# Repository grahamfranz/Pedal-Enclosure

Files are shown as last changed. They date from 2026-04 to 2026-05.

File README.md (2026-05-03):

# Parametric Guitar Pedal Enclosure

A fully customizable 3D-printable guitar pedal enclosure designed in OpenSCAD, inspired by classic Hammond die-cast boxes. Create professional-looking enclosures in multiple standard sizes or define your own custom dimensions.

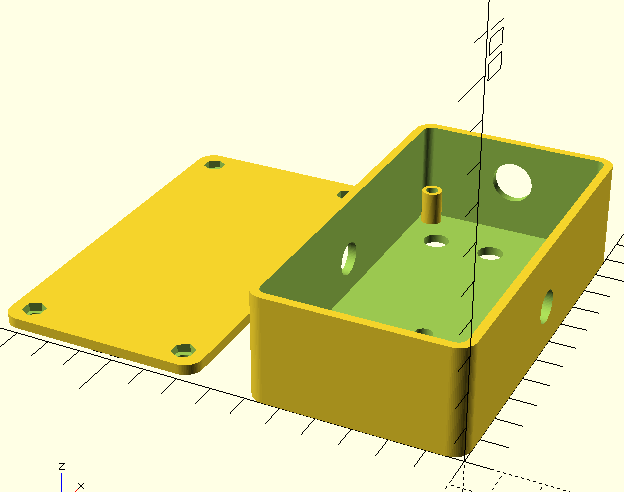
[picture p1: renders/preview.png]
Pedal Enclosure Preview


## Features

- **Parametric Design**: Adjust every dimension and component hole size via the OpenSCAD Customizer
- **Multiple Presets**: Choose from Hammond standard sizes (1590A, 1590B, 1590BB, 125B) or design custom dimensions
- **Two-Part Assembly**: Open-bottom shell with removable lid for easy component mounting
- **Complete Controls**: Pre-configured holes for:
  - Potentiometer knobs (configurable count and positions)
  - Footswitch
  - LED indicator
  - 1/4" input and output audio jacks
  - DC barrel jack for power
- **Screw Bosses**: Built-in corner screw mounting posts with configurable counterbores
- **Smooth Curves**: Rounded corners and edges for a professional finish
- **Print-Ready**: Includes flipping options to optimize for 3D printing

## Getting Started

### Requirements

- **OpenSCAD** (free, open-source 3D CAD tool): [Download](https://openscad.org/)
- A 3D printer or 3D printing service

### Installation

1. Clone the repository:
   ```bash
   git clone https://github.com/grahamfranz/Pedal-Enclosure.git
   cd Pedal-Enclosure
   ```

2. Open `pedal_enclosure.scad` in OpenSCAD

## Usage

### Quick Start with Presets

1. In OpenSCAD, go to **Window > Customizer**
2. Under the `[Preset]` section, select a preset size:
   - `1590A` - Small (92.5 × 38.5 × 31 mm)
   - `1590B` - Medium (112 × 60 × 31 mm) — *default*
   - `1590BB` - Large (119 × 94 × 34 mm)
   - `125B` - XL (121 × 66 × 39 mm)
3. Choose a render option under `[Render]`:
   - `enclosure` - Just the main shell (top side up)
   - `lid` - Just the bottom plate (base plate up)
   - `both` - Both parts positioned for printing (with default flip options)
   - `assembled` - Parts together to see the final result
4. The default settings use **hex nut fasteners, board standoffs enabled, no corner bosses, and flipped print orientation** — ideal for most builds
5. Click **F5** to preview or **F6** to render
6. Export as STL when ready to print

### Custom Dimensions

1. Set `preset` to `custom`
2. Enter your desired dimensions in the `[Custom Outer Size]` section:
   - `custom_length` - X axis (long direction)
   - `custom_width` - Y axis (short direction)
   - `custom_height` - Z axis (vertical)

### Customize Components

The Customizer provides sections for fine-tuning:

- **[Shell]** - Wall thickness, corner radius, smoothness
- **[Screw Mounting]** - Boss type (on/off), diameter, inset, clearances, counterbores, and fastener type (`self_tap`, `hex_nut`, `square_nut`)
- **[Lid Locating Lip]** - A raised plug on the lid that drops into the enclosure cavity, preventing lid shear under foot pressure
- **[Board Mount]** - Standoff diameter and height (optional posts hanging from the top wall for proto board mounting)
- **[Top: Knobs]** - Number of knobs (auto-distributes across rows), center-to-center spacing, hole diameter, row spacing
- **[Top: Footswitch]** - Hole size and position
- **[Top: LED]** - Hole diameter and position (optional)
- **[Sides: Audio Jacks]** - Hole sizes, heights, and symmetric offset to prevent jack hardware collision
- **[Back: DC Jack]** - Hole size and height (optional)

### Coordinate System

The design uses a standard orientation (top-down view):

```
      +X  (back edge — DC jack)
   +-------------------+
   |       [dc]        |
   |  o   o   o   o    | knob row
[O]|                   |[I] -Y = output, +Y = input
   |        *          | LED
   |                   |
   |       ( X )       | footswitch
   |                   |
   +-------------------+
      -X  (toe)
```

## Printing Tips

- **Enclosure orientation**: Controlled by `flip_enclosure_for_print` (default `true` — top face on bed for the cleanest finish on the labeled side)
- **Lid orientation**: Controlled by `flip_lid_for_print` (default `true` — nut pockets face upward, away from the bed, so they don't sag during printing; the raised locating plug prints first as a solid foundation)
- **Support Material**: With both flip options on, neither part needs supports
- **Tolerance**: Adjust `lid_clearance_d` and `screw_hole_d` if you have fit issues with your printer
- **Wall Thickness**: For durability, keep at least 2–2.5 mm walls
- **Lid thickness**: Use at least 3 mm when using hex/square nut modes; the raised lip will be `lip_height` taller (default 1.5 mm)
- **Locating lip fit**: The plug is sized to the cavity inner profile minus 0.3 mm clearance so it slips in smoothly without binding

## Assembly

### Fastener Options

Choose a method in the `[Screw Mounting]` section:

| `boss_fastener` | Hardware needed | Notes |
|---|---|---|
| `self_tap` | M3 self-tapping screws (from below) | Simple, but repeated opening/closing will eventually strip the plastic |
| `hex_nut` *(default)* | M3 hex nuts + M3 machine screws (from above) | Screw enters the top face, passes down through the corner, and threads into a hex nut pocket captive in the lid's underside — provides reusable fastening |
| `square_nut` | M3 square nuts + M3 machine screws (from above) | Same as hex, but with a square pocket which is easier to print accurately |

**Note:** Nut modes recess the nut pocket into the lid's underside, so set `lid_thickness` to at least `nut_pocket_depth + 0.6` mm (default 3 mm is recommended for M3).

For nut modes, set `nut_pocket_depth` to match your nut (hex ≈ 2.4 mm, square ≈ 1.8 mm).

### Assembly Steps

1. Print both parts (use default flip settings for cleanest results)
2. *(Hex/square nut modes only)* Drop an M3 nut into each nut pocket on the lid's underside
3. Install your components (pots, jacks, footswitch, LED) into the pre-drilled holes
4. *(Optional: board standoffs)* Insert your proto board (e.g., CircuitMesh) from below the enclosure, aligning its screw holes with the standoffs, then secure from underneath
5. Insert screws from the top into the corner posts and tighten (they will thread into the nut pockets on the lid's underside)
6. Mount the lid to close the enclosure — the raised locating plug will drop into the cavity for a snug, shear-resistant fit

## Pre-Rendered STL Files

All preset Hammond enclosures are available as pre-rendered STLs in the `renders/` directory, ready for immediate 3D printing. Each preset is exported in three configurations:

| Preset | Size (mm) | Enclosure | Lid | Both |
|---|---|---|-----|---|
| **1590A** | 92.5 × 38.5 × 31 | `1590A_enclosure.stl` | `1590A_lid.stl` | `1590A_both.stl` |
| **1590B** | 112 × 60 × 31 | `1590B_enclosure.stl` | `1590B_lid.stl` | `1590B_both.stl` |
| **1590BB** | 119 × 94 × 34 | `1590BB_enclosure.stl` | `1590BB_lid.stl` | `1590BB_both.stl` |
| **125B** | 121 × 66 × 39 | `125B_enclosure.stl` | `125B_lid.stl` | `125B_both.stl` |

**Note**: All presets default to 3 knobs. You can customize `num_knobs` in the Customizer for any preset — the layout automatically wraps to multiple rows as needed.

### Quick Print Guide

- **Use `*_both.stl` files** for a complete assembly view with both parts positioned for printing
- **Use individual `*_enclosure.stl` and `*_lid.stl` files** if you prefer to print them separately or scale one part differently

## File Structure

```
Pedal-Enclosure/
├── README.md                  # This file
├── LICENSE                    # MIT License
├── pedal_enclosure.scad       # Main OpenSCAD design
└── renders/
    ├── preview.png            # Visual preview
    ├── 1590A_enclosure.stl     # Pre-rendered STL (small, 2 knobs)
    ├── 1590A_lid.stl
    ├── 1590A_both.stl
    ├── 1590B_enclosure.stl     # Pre-rendered STL (medium, 3 knobs)
    ├── 1590B_lid.stl
    ├── 1590B_both.stl
    ├── 1590BB_enclosure.stl    # Pre-rendered STL (large, 3 knobs)
    ├── 1590BB_lid.stl
    ├── 1590BB_both.stl
    ├── 125B_enclosure.stl      # Pre-rendered STL (XL, 3 knobs)
    ├── 125B_lid.stl
    └── 125B_both.stl
```

## Customization Examples

### Reduce Material: Thin-Walled Version
- Decrease `wall_thickness` to 1.5 mm
- Decrease `lid_thickness` to 1.2 mm

### Smoother Finish: High-Detail Render
- Increase `facets` from 72 to 96 or higher (slower render)

### More Knobs
- Increase `num_knobs` to any value. The layout automatically wraps knobs to multiple rows based on enclosure width
- Adjust `knob_spacing` (center-to-center distance) and `knob_row_spacing` (vertical gap between rows) as needed
- Rows with different knob counts are horizontally centered (staggered effect); rows with the same count align vertically

### Offset Audio Jacks
- Use `jack_x_offset` to prevent 1/4" jack connectors from colliding (typical range: ±15 mm)
- Positive values move the input jack forward and output jack back
- Negative values reverse the direction
- Useful for compact builds where jack hardware extends into the enclosure

### Hide Optional Components
- Set `include_led` to `false` to remove the LED hole
- Set `include_dc_jack` to `false` to remove the DC jack

## Contributing

Feel free to fork, modify, and share improvements. If you have suggestions or find issues, please open an issue on GitHub.

## Credits

Designed by Graham Franz. Inspired by the classic Hammond die-cast enclosure series.

---

**Tips**: For the best results, always preview your design in OpenSCAD before printing. Test-fit your components (pots, jacks) in the STL file to ensure proper spacing and clearance.

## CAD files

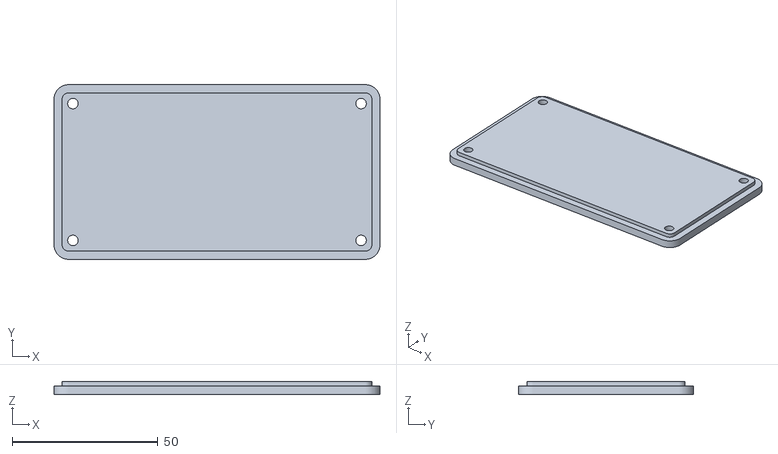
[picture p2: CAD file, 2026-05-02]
renders/1590B_lid.stl
112.0 x 60.0 x 4.50

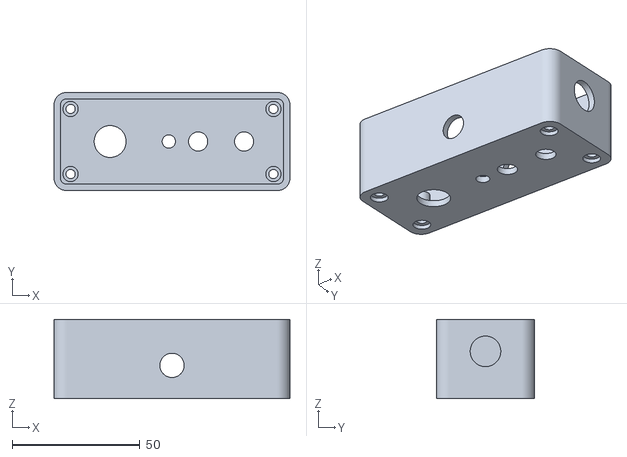
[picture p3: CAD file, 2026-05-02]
renders/1590A_enclosure.stl
92.5 x 38.5 x 31.0

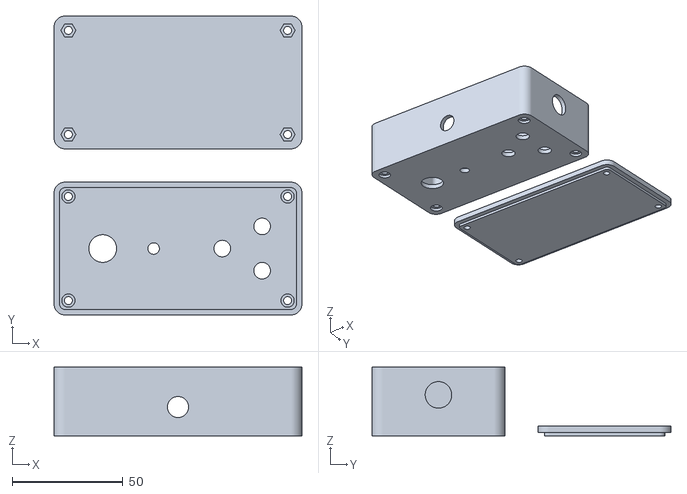
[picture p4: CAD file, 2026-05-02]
renders/1590B_both.stl
112.0 x 135.0 x 31.0

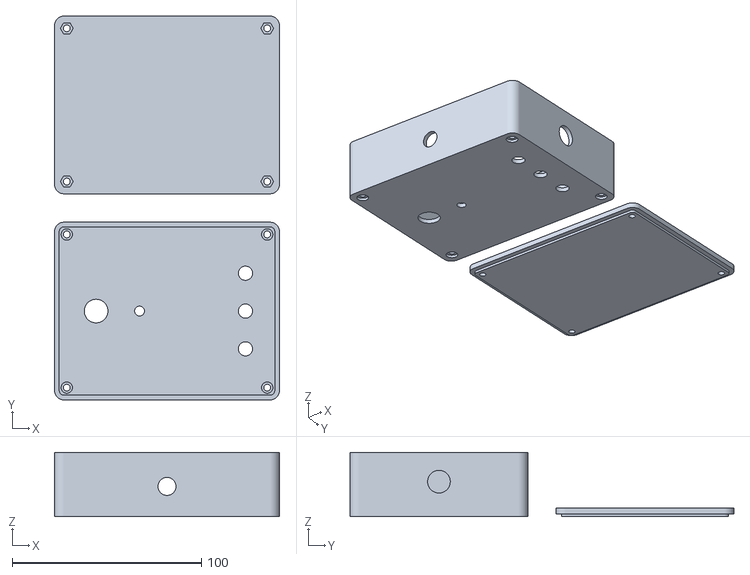
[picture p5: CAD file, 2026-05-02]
renders/1590BB_both.stl
119.0 x 203.0 x 34.0

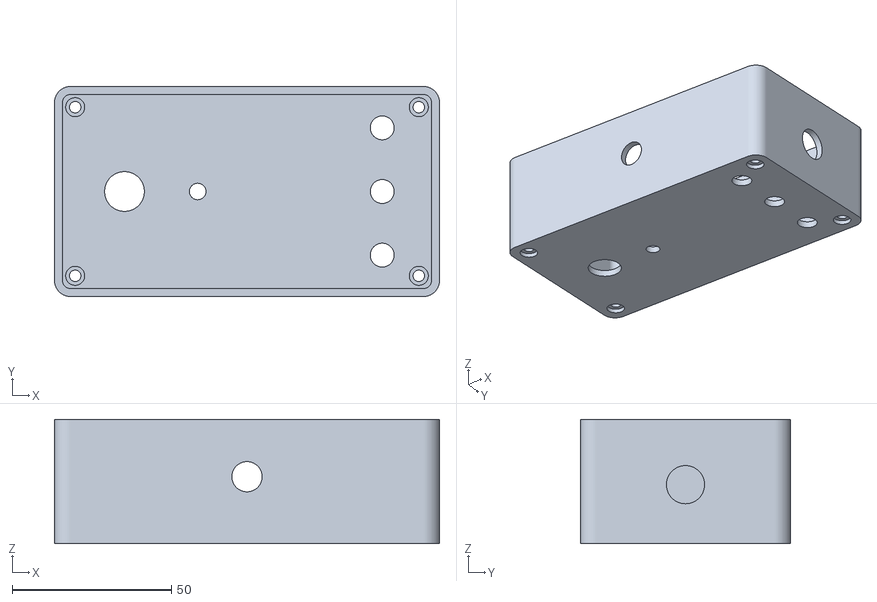
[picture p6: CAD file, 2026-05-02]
renders/125B_enclosure.stl
121.0 x 66.0 x 39.0

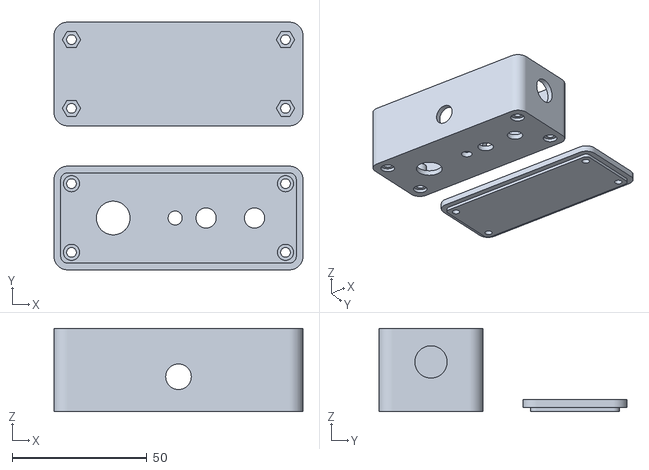
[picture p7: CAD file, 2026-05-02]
renders/1590A_both.stl
92.5 x 92.0 x 31.0

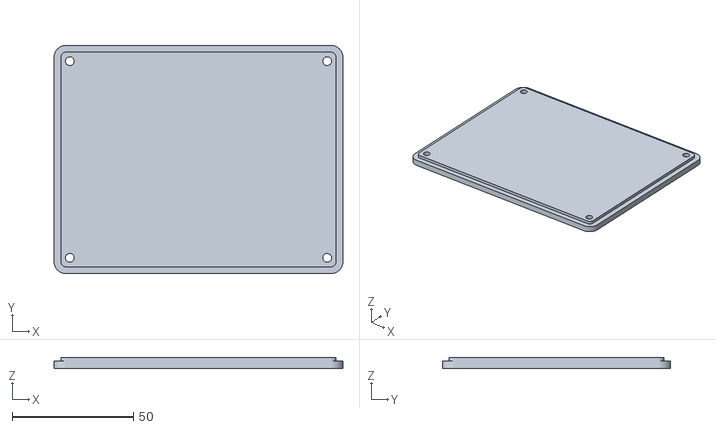
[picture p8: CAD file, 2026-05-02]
renders/1590BB_lid.stl
119.0 x 94.0 x 4.50

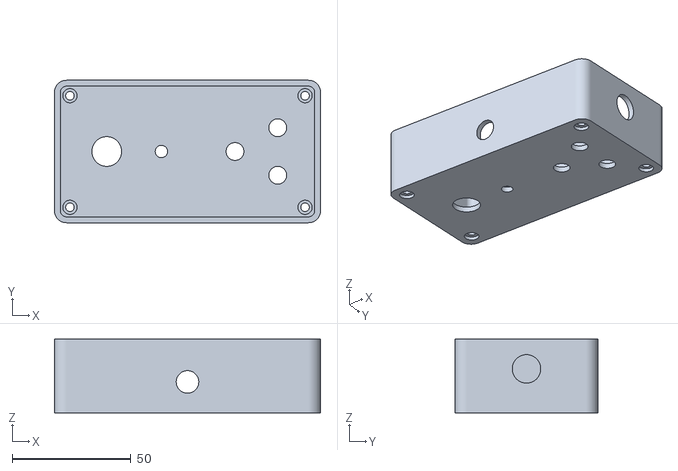
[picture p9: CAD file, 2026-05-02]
renders/1590B_enclosure.stl
112.0 x 60.0 x 31.0

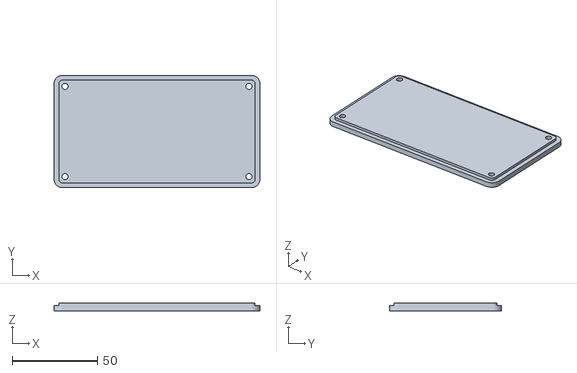
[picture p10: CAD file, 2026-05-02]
renders/125B_lid.stl
121.0 x 66.0 x 4.50

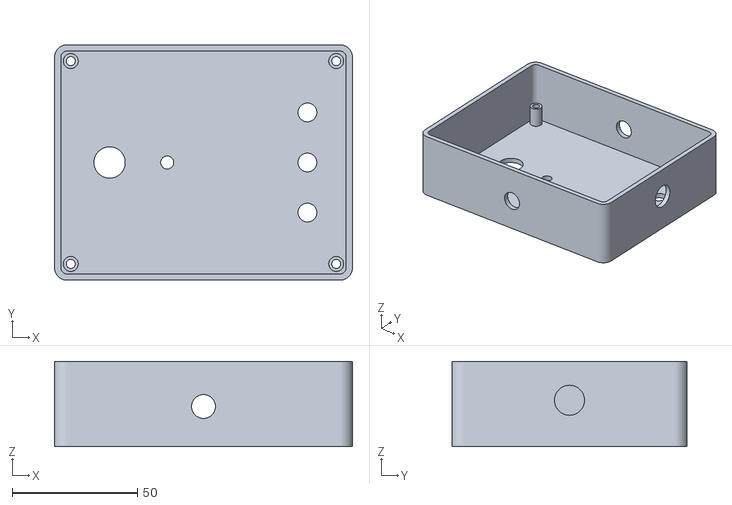
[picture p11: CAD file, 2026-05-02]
renders/1590BB_enclosure.stl
119.0 x 94.0 x 34.0

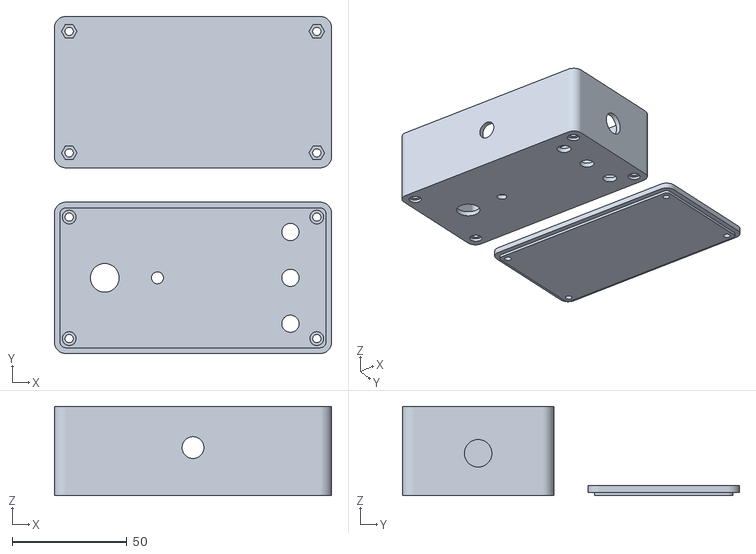
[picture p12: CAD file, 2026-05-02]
renders/125B_both.stl
121.0 x 147.0 x 39.0

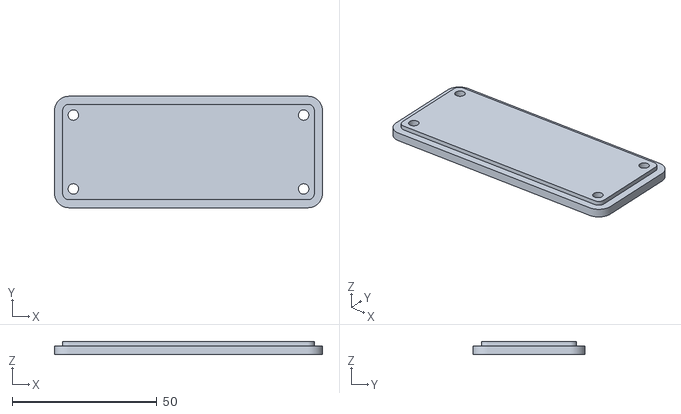
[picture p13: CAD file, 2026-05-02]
renders/1590A_lid.stl
92.5 x 38.5 x 4.50

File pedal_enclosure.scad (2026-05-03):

/* ============================================================
 *  Parametric Guitar Pedal Enclosure
 *  ------------------------------------------------------------
 *  Inspired by Hammond die-cast boxes (1590A / 1590B / 1590BB /
 *  125B). Open-bottom shell with a removable lid, corner screw
 *  bosses, and all the usual holes for pots, footswitch, LED,
 *  1/4" jacks and a DC barrel jack.
 *
 *  Layout (top-down view, looking at the top face):
 *
 *        +X  <-- back edge (DC jack)
 *     +-------------------+
 *     |       [dc]        |
 *     |  o   o   o   o    |   knob row
 *  [O]|                   |[I]   -Y = output,  +Y = input
 *     |        *          |   LED
 *     |                   |
 *     |       ( X )       |   footswitch
 *     |                   |
 *     +-------------------+
 *        -X  <-- toe
 *
 *  Tweak everything in the Customizer panel (Window > Customizer
 *  in OpenSCAD) or edit the variables below.
 * ============================================================ */

/* [Preset] */
// Pick a common Hammond size, or choose "custom" to use the fields below.
preset = "1590B"; // [custom, 1590A, 1590B, 1590BB, 125B]

/* [Render] */
// Which part to render.
part = "both"; // [enclosure, lid, both, assembled]
// Flip the enclosure so the top face is on the bed (cleanest finish for the
// labeled face). Either way each part's print-bottom sits on Z = 0.
flip_enclosure_for_print = true;
// Flip the lid so any recesses (nut pockets or counterbores) face away from
// the bed — they bridge cleanly when printed open-side up.
flip_lid_for_print = true;

/* [Custom Outer Size — used when preset = "custom"] */
custom_length = 112;  // along X (long axis)
custom_width  = 60;   // along Y
custom_height = 31;   // along Z

/* [Shell] */
wall_thickness = 2.5;
lid_thickness  = 3.0;  // bump to ≥ nut_pocket_depth + 0.6 mm when using nut modes
corner_radius  = 5;
// Smoothness — higher = prettier curves, slower render.
facets = 72;

/* [Lid Locating Lip] */
// A stepped flange on the lid perimeter that sits on the enclosure rim,
// preventing shear and keeping the lid aligned.
include_lip = true;
lip_height  = 1.5;  // height of the perimeter flange (mm)

/* [Screw Mounting] */
// How the lid screws fasten into the corner bosses.
include_screw_bosses = false; // set false to free corner space for a full-width board
boss_fastener   = "hex_nut"; // [self_tap, hex_nut, square_nut]
screw_hole_d    = 2.7;   // pilot hole for self_tap (M3 → 2.7 mm)
screw_boss_d    = 8;     // corner boss outside diameter
screw_inset     = 6;     // distance from outer wall to boss centre
lid_clearance_d = 3.6;   // M3 free-fit through the lid (also used as boss clearance for nut modes)
lid_counterbore = true;  // recess the screw heads into the lid
// Nut pocket — used when boss_fastener is "hex_nut" or "square_nut".
// Pocket is recessed into the BOTTOM (outside) face of the lid, so make sure
// lid_thickness is at least nut_pocket_depth + ~0.6 mm of plastic on top.
nut_af          = 5.5;   // across-flats dimension (M3 standard hex/square = 5.5 mm)
nut_pocket_depth = 2.4;  // M3 hex ≈ 2.4 mm, M3 square ≈ 1.8 mm

/* [Board Mount] */
// Raised standoffs inside the enclosure for mounting a CircuitMesh or other proto board.
board_standoffs       = true;
board_standoff_height = 10;   // distance from the top-wall underside to the board (mm)
board_standoff_d      = 6;    // standoff post diameter (mm)
board_screw_margin    = 4;    // from inner wall corner to standoff centre — match your board's value
board_pilot_d         = 2.7;  // M3 self-tap pilot drilled up into the standoff

/* [Top: Knobs] */
num_knobs          = (preset == "1590A") ? 2 : 3;  // auto-adjust for tight 1590A, override in Customizer if needed
knob_hole_d        = 7.5;   // 3/8" pot bushing clearance
knob_spacing       = 20;    // center-to-center distance between knob holes (static, doesn't scale)
knob_row_spacing   = 18;    // center-to-center vertical distance between knob rows
knob_row_from_back = 18;    // distance of first (topmost) knob row from +X wall
knob_side_margin   = 13;    // distance from first/last knob to long side (Y axis)

/* [Top: Footswitch] */
footswitch_hole_d     = 12.5;  // 12 mm stomp switch
footswitch_from_front = 22;    // distance from -X wall

/* [Top: LED] */
include_led    = true;
led_hole_d     = 5.2;    // 5 mm LED pass-through (use ~8.2 for bezel)
led_from_front = 45;

/* [Sides: Audio Jacks] */
input_jack_d         = 9.5;   // 1/4" enclosed jack
output_jack_d        = 9.5;
jack_height_from_lid = 15;    // centre height above the lid seat
jack_x_offset        = 0;     // symmetric offset in mm; positive = input forward, output back
                              // typical range: ±15 mm (beyond ±20 mm risks hitting walls/bosses)

/* [Back: DC Jack] */
include_dc_jack        = true;
dc_jack_d              = 12;   // 2.1 mm barrel jack with panel boss
dc_jack_board_offset   = -6;    // barrel jack centre height above the board surface

/* [Hidden] */
$fn = facets;
EPS = 0.02;

// ============================================================
//  Geometry
// ============================================================

function _preset_dims() =
    preset == "1590A"  ? [92.5, 38.5, 31] :
    preset == "1590B"  ? [112,   60,   31] :
    preset == "1590BB" ? [119,   94,   34] :
    preset == "125B"   ? [121,   66,   39] :
                         [custom_length, custom_width, custom_height];

_dims = _preset_dims();
L = _dims[0];
W = _dims[1];
H = _dims[2];

// Auto-calculate DC jack height to align with a board-mounted barrel jack.
dc_jack_height_from_lid = H - wall_thickness - board_standoff_height + dc_jack_board_offset - lid_thickness;

echo(str("Outer size: ", L, " x ", W, " x ", H, " mm"));

// Sanity check: nut pocket must fit inside the lid with some plastic on top.
if ((boss_fastener == "hex_nut" || boss_fastener == "square_nut")
    && lid_thickness < nut_pocket_depth + 0.6)
    echo(str("WARNING: lid_thickness (", lid_thickness,
             ") is too thin for the ", boss_fastener, " pocket (",
             nut_pocket_depth, " mm). Bump lid_thickness to at least ",
             nut_pocket_depth + 0.6, " mm."));

// ---------- helpers ----------

module rounded_prism(l, w, h, r) {
    rr = max(0.1, min(r, min(l, w) / 2 - 0.1));
    hull() for (x = [rr, l - rr], y = [rr, w - rr])
        translate([x, y, 0]) cylinder(r = rr, h = h);
}

function _corner_points() = [
    [screw_inset,     screw_inset    ],
    [L - screw_inset, screw_inset    ],
    [screw_inset,     W - screw_inset],
    [L - screw_inset, W - screw_inset]
];

function _board_standoff_points() = [
    [wall_thickness + board_screw_margin, wall_thickness + board_screw_margin              ],
    [L - wall_thickness - board_screw_margin, wall_thickness + board_screw_margin          ],
    [wall_thickness + board_screw_margin, W - wall_thickness - board_screw_margin          ],
    [L - wall_thickness - board_screw_margin, W - wall_thickness - board_screw_margin      ]
];

// Multi-row knob layout helpers.
// Calculate how many knobs fit in one row given available width.
function _knobs_per_row() =
    num_knobs == 0 ? 0 :
    let(available_width = W - 2 * knob_side_margin)
    floor((available_width + knob_spacing) / knob_spacing);

// Calculate the actual row spacing, auto-reducing if enclosure is too short.
function _effective_knob_row_spacing() =
    let(kpr = _knobs_per_row(),
        num_rows = kpr == 0 ? 0 : ceil(num_knobs / kpr))
    num_rows <= 1 ? knob_row_spacing :
    let(available_length = L - knob_row_from_back - led_from_front - knob_hole_d/2 - led_hole_d/2 - 5,
        max_spacing = available_length / max(1, num_rows - 1))
    min(knob_row_spacing, max_spacing);  // Use calculated spacing if smaller

// Return list of [x, y, row, col] for each knob position.
function _knob_positions() =
    let(kpr = _knobs_per_row(),
        available_width = W - 2 * knob_side_margin,
        effective_spacing = _effective_knob_row_spacing())
    kpr == 0 ? [] :
    [for (i = [0 : num_knobs - 1])
        let(row = floor(i / kpr),
            col = i - row * kpr,
            knobs_in_row = min(kpr, num_knobs - row * kpr),
            // Width occupied by knobs in this row
            row_width = (knobs_in_row - 1) * knob_spacing,
            // Center offset to align row to enclosure
            row_offset_y = (available_width - row_width) / 2,
            // Y position (centered per row, then add side margin)
            yk = knob_side_margin + row_offset_y + col * knob_spacing,
            // X position (from back, accounting for row with effective spacing)
            xk = L - knob_row_from_back - row * effective_spacing)
        [xk, yk, row, col]
    ];
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

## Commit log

2026-04-28 Initial commit: parametric pedal enclosure with preset Hammond sizes
    Fully customizable guitar pedal enclosure with:
    - 4 preset Hammond sizes (1590A, 1590B, 1590BB, 125B)
    - Pre-rendered STL files ready for 3D printing
    - Complete OpenSCAD parametric design
    - Support for custom dimensions and components
    [125B_both.stl, 125B_enclosure.stl, 125B_lid.stl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]
2026-05-02 Add multi-row knob layout support
    - Add knob_spacing (static center-to-center spacing) and knob_row_spacing parameters
    - Implement automatic knob distribution across multiple rows based on enclosure width
    - Rows with different knob counts are horizontally centered (staggered effect)
    - Rows with same knob counts align vertically
    - Knob positioning now scales with enclosure dimensions while maintaining consistent spacing
    [pedal_enclosure.scad]
2026-05-02 Make num_knobs a customizable parameter
    Allow num_knobs to appear in OpenSCAD Customizer by using a simple assignment
    instead of a conditional expression. Default is 3.
    [pedal_enclosure.scad]
2026-05-02 Remove LICENSE file and update SCAD header
    - Remove LICENSE file (rely on GitHub repo license setting)
    - Remove license comment from SCAD file header
    - Re-render all preset STLs with updated code
    [125B_both.stl, 125B_enclosure.stl, 125B_lid.stl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]
2026-05-02 Auto-adjust knob row spacing for compact enclosures
    Calculate effective row spacing based on available length to prevent knobs
    from overlapping with the footswitch on smaller enclosures like 1590A.
    Maintains configurable knob_row_spacing as default but scales down when needed.
    [125B_both.stl, 125B_enclosure.stl, 125B_lid.stl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]
2026-05-02 Fix knob spacing to account for LED position
    Use led_from_front as the constraint for knob row spacing instead of
    footswitch_from_front, since LED is between the knob rows and footswitch.
    This prevents knobs from overlapping the LED on compact enclosures.
    [125B_both.stl, 125B_enclosure.stl, 125B_lid.stl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]
2026-05-02 Change default knob count from 3 to 2
    1590A is too tight for 3 knobs with proper spacing. 2 knobs is a better
    default for all presets, and users can still customize num_knobs higher
    for larger enclosures if desired.
    [125B_both.stl, 125B_enclosure.stl, 125B_lid.stl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]
2026-05-02 Restore preset-specific knob defaults
    1590A defaults to 2 knobs (tight fit), other presets default to 3 knobs.
    Users can override num_knobs in the Customizer for any preset.
    [125B_both.stl, 125B_enclosure.stl, 125B_lid.stl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]
2026-05-03 Add symmetric jack_x_offset parameter for offsetting audio jack holes
    [pedal_enclosure.scad]
